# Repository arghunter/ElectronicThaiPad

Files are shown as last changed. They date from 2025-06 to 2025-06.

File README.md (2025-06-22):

# Electronic Thai Pad

A Thai pad that records and displays how hard you hit it with a strip of LEDs.

**What is a thai pad?**
- A thai pad is a handheld pad for kicking and punching
- However, it can be hard to guage how hard you are hitting to track your improvement



**What this electronic thai pad does**
- This project embedded an IMU (accelerometer) and a number of piezo sensors within a thai pad to detect the strengh of hits.
- It then uses an LED strip surrounding the pad to display visually the strength of hits
- Additionally, aim is very important, so the 5 piezo sensors, spread in a pentagon, can be used to highlight where on the pad your strike lands in order to help you center your following strikes

**Why I made this proejct**
As a fourth degree black belt, I value every source of feedback, but objective feedback can be difficult and expensive to acquire, so this is a cheap and low cost way to acquire objective feedback on my techniques.

## Pictures
### Full Project
- I would provide a 3d model, but it would just be an image of a thai pad, this system is mean to be fully embedded. However, below is a sketch of the sensor positioning. Additionally, the microcontroller will be surrounded in a TPU case to protect it from the repeated shocks.
- Note: These are meant to be flexible as there are many variation of thai pad designs.

### Wiring Diagram
- As the thai pad is rather large, a PCB will not work, instead I have attached a wiring diagram.


## BOM
| Part | Cost | Count | Notes | Link | Total |
|---|---|---|---|---|---|
| Adafruit Feather nRF52840 Sense | $39.50  | 1 | Already Owned | [Link](https://www.adafruit.com/product/4516) | $0.00 |
| Li-Po Battery | $5.95 | 1 | Already Owned | [Link](https://www.adafruit.com/product/4237) | $0.00 |
| STEVAL-MKI251A | $16.81  | 1 | Free Shipping | [Link](https://estore.st.com/en/steval-mki251a-cpn.html) | $16.81  |
| Piezo Sensor | $2.32 | 1 | 5-Pack | [Link](https://www.aliexpress.us/item/3256808935246513.html) | $2.32 |
| Neopixel Light Strip | $9.18 | 1 | 2m 60 | [Link](https://www.aliexpress.us/item/2251801850504415.html) | $9.18 |
| | | | | | |
| **Total:** | | | | | **$28.49** |

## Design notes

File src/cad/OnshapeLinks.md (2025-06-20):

Microcontroller Case: https://cad.onshape.com/documents/dade0f93471fa8ff7ce986ea/w/0de7b6a36b37bba335ba1247/e/2264d750831debf76f0489bb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

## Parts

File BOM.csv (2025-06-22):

Part | Cost | Count | Notes | Link | Total
Adafruit Feather nRF52840 Sense | $39.50 | 1 | Already Owned | https://www.adafruit.com/product/4516 | $0
Li-Po Battery | $5.95 | 1 | Already Owned | https://www.adafruit.com/product/4237 | $0
STEVAL-MKI251A | $16.81 | 1 | Free Shipping | https://estore.st.com/en/steval-mki251a-cpn.html | $16.81
Piezo Sensor | $2.32 | 1 | 5-Pack | https://www.aliexpress.us/item/3256808935246513.html | $2.32
Neopixel Light Strip | $9.18 | 1 | 2m 60 | https://www.aliexpress.us/item/2251801850504415.html | $9.18
Total: |  |  |  |  | $28.49

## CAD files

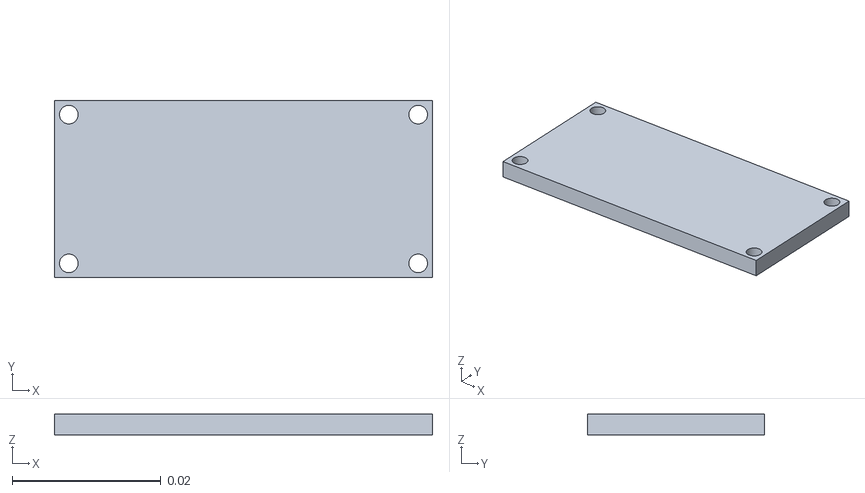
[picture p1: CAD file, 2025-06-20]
src/cad/MicrontrollerCaseTop.stl
0.0508 x 0.0239 x 0.0028

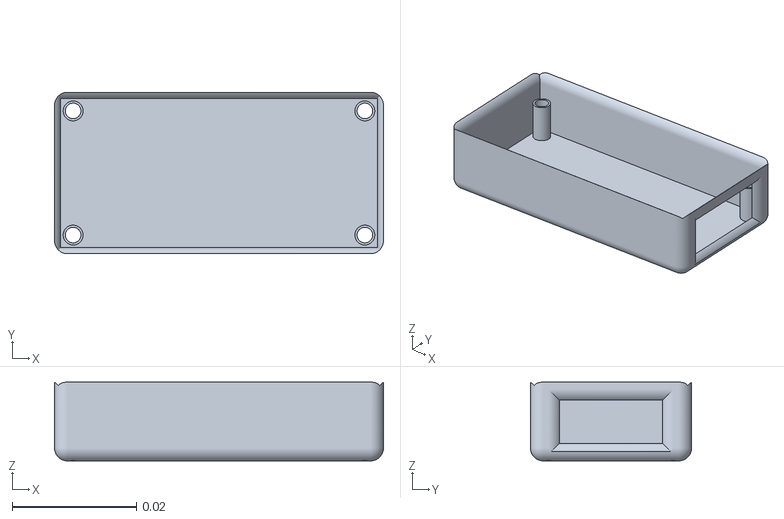
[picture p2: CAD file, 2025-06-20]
src/cad/MicrontrollerCaseBottom.stl
0.053 x 0.026 x 0.0127

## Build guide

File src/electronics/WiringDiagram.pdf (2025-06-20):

# Electronic Thai Pad Wiring

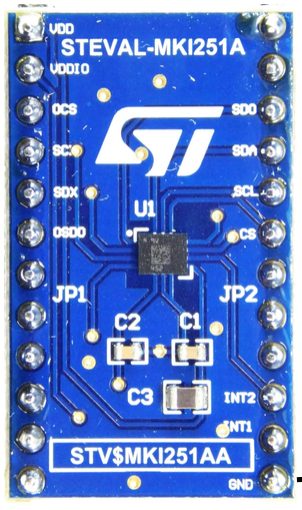
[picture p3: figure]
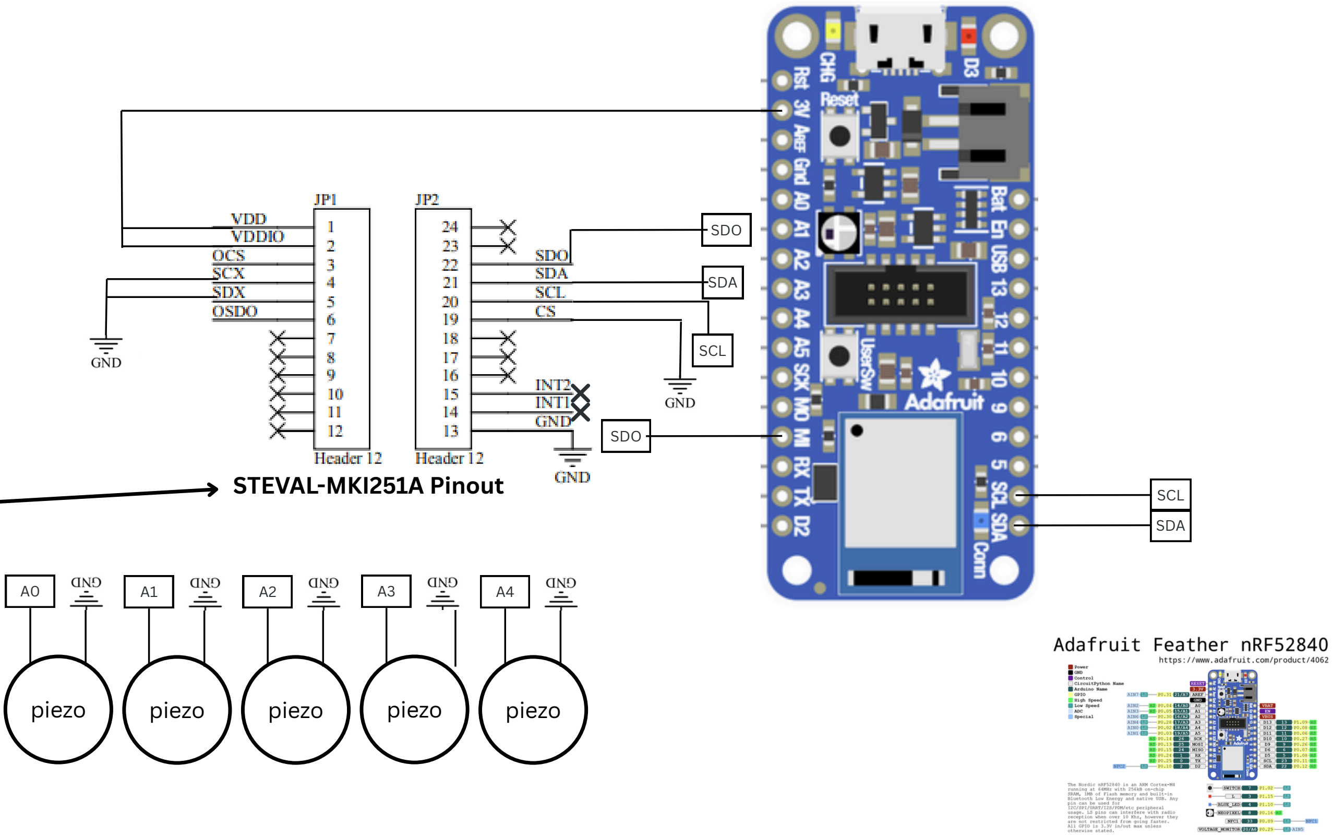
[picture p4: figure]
STEVAL-MKI251A Pinout; SDA; SCL; SDO; piezo

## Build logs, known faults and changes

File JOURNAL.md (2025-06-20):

---
title: "Electronic Thai Pad"
author: "Armaan Gomes"
description: "A Muay Thai Pad that uses a set of sensors to detect and respond to the strength of the hits."
created_at: "2025-06-9"
---

# June 9th
## Planning: 
- Needs to register hits
    - First Idea: IMU - Already have some Adafruit nrf 52840 sense boards (https://learn.adafruit.com/adafruit-feather-sense/overview) that would be great
    - Other Ideas:
        - Piezo sensors -  plan to hook up 4/5 to the ADCs of the nrf board for more detailed pressure/strike detection - Note: might need some voltage protection
        - FSR (Force Sensistive Resistors - A friend used these in one of their projects, but reportedly they aren't very precise, so probably won't use them.
     
- Signalling
    - LED strip around pad, neopixels embedded within pad below the fabric surface,
    - Can use bluetooth for web interface
    - First prototype will probably use serial while initial testing
 - Power
     - The nrf sense board already have a battery hookup and charger for lipo batteries
  
- Probably won't need a PCB just because the nrf sense boards already work so well.

## Programming:
- Found boards, updated bootloader
- Tried out the adafruit sensor demo
    - Took way to long to get the correct libaries installed
    -  
    - Need to note that the acceleration also includes gravity when stationary so I may need to offset that later
-  After that, tired out neopixel demo, needed to find correct neopixel configuration to use the onboard pin
-  Combined the two to make a system that reflects both the direction and magnitude of the acceleration on the IMu built into the board
    - Forgot to accout for negatives, which confused me for a bit
    - Squaring the values caused it to become too sensitive and also flashbang me,
    - Settled on less sensitive brightness and color control, with offsets to account for stationary moments.
        - Stationary:
            - Dim and single color
            - 
        - Accelerating:
            - Much brighter and between primary colors
            -   

## Pad Acquisition:
- I talked to my taekwondo instructor and he gave me 4 old pads to experiment with
    - 
## Initial Testing
- Shoved the sense board (feather) into the pad
    - Kinda messy for a first test but if it work it works. Note will need padding to protect board from impact
    - 
- Did a tad more coding, intially to use the serial plotter, but that sucks so I got a serial decoder in python and am using that for testing
- It works - But now I appear to be maxing out the sensor:
    - Despite hitting with different power, the accel always seems to be suspiciously similar 
    -  
    -  Read the data sheet and it looks like the imu is set to +-4G of acceleration so I need to find a way around that.
    -  Ok I found a way to increase the accel range to 16g, which is the max. SAadly, I'm still maxing it on some punches, maybe i should try some padding
        -    
- Padding in front of the sensor did not work, I think i need some sort of springy substance both infront and behind the sensor to act as mechanical dampers.

## Cadding
- I made a rough case that has a space for a sliding platform with springs to dampen impact.
- However, i am currently failing at both making a screw and making a spring I am using the sweep tool wrong somehow and will figure it out later
- 

1h planning (probably a little more than this)+1h coding + 0.5h Pad Acquisition+ 2h initial testing + 1 h CADding

**Time Spent: 5.5h**

# June 10th
## Cad Pain
- I really need to learn CAD for real.
- I got a spring set up in possible the most awful way posible
- Then for somethin reason I thought I could print this in 1 piece without supports
    - 
 - I also failed at screws again so I settled for dowels
 - I am also suspecting that I will need a high-G IMU like https://blog.st.com/lsm6dsv320x/
     - Its also smd so I have no shot of soldering that myself, so I'll probably need the expansion board
- Slice and printed for testing
    - 

1h Cadding + 0.5h Research/Parts Search
   
**Time Spent: 1.5h**

# June 12th
## Assembly
- Not too deep, everything generally fits. The dowels didn't print very well but thats fine.
  - 
  - 
  
## Wiring Diagram
-  Datasheet for imu: https://www.st.com/resource/ja/datasheet/lsm6dsv320x.pdf
-  Started work

**Time Spent: 0.5h**

# June 20th
## Wiring Diagram
- Made the wiring diagram, looked through datasheets and connected everything correctly
- Plan to directly solder to microcontroller due to the large distance from the micrcontroller to the peripherals
    -  May use a perf board if the wiring becomes too hairy.
 
## Case
- Minor tweaks, added stl files to repo, plan to print in TPU

**Time Spent: 1h**

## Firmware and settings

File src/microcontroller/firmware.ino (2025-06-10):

#include <Adafruit_LSM6DS33.h>
#include <Adafruit_LSM6DS3TRC.h>
#include <Adafruit_NeoPixel.h>


Adafruit_LSM6DS3TRC lsm6ds3trc; // accelerometer, gyroscope
Adafruit_LSM6DS33 lsm6ds33;

#define LED_PIN     8

#define LED_COUNT  1

#define BRIGHTNESS 50 // Set BRIGHTNESS to about 1/5 (max = 255)


Adafruit_NeoPixel strip(LED_COUNT, LED_PIN, NEO_GRBW + NEO_KHZ800);



float accel_x, accel_y, accel_z;
float gyro_x, gyro_y, gyro_z;


long int accel_array[6];
long int check_array[6]={0.00, 0.00, 0.00, 0.00, 0.00, 0.00};



bool new_rev = true;

void setup(void) {
  Serial.begin(115200);






  lsm6ds33.begin_I2C();
  lsm6ds33.setAccelRange(LSM6DS_ACCEL_RANGE_16_G);
  // check for readings from LSM6DS33
  sensors_event_t accel;
  sensors_event_t gyro;
  sensors_event_t temp;
  lsm6ds33.getEvent(&accel, &gyro, &temp);
  accel_array[0] = accel.acceleration.x;
  accel_array[1] = accel.acceleration.y;
  accel_array[2] = accel.acceleration.z;
  accel_array[3] = gyro.gyro.x;
  accel_array[4] = gyro.gyro.y;
  accel_array[5] = gyro.gyro.z;

  for (int i =0; i < 5; i++) {
    if (accel_array[i] != check_array[i]) {
      new_rev = false;
      break;
    }
  strip.begin();           // INITIALIZE NeoPixel strip object (REQUIRED)
  strip.show();            // Turn OFF all pixels ASAP
  strip.setBrightness(BRIGHTNESS);
  }
  // and we need to instantiate the LSM6DS3TRC
  if (new_rev) {
    lsm6ds3trc.begin_I2C();
  }


}

void loop(void) {

  sensors_event_t accel;
  sensors_event_t gyro;
  sensors_event_t temp;
  if (new_rev) {
    lsm6ds3trc.getEvent(&accel, &gyro, &temp);
  }
  else {
    lsm6ds33.getEvent(&accel, &gyro, &temp);
  }
  accel_x = accel.acceleration.x;
  accel_y = accel.acceleration.y;
  accel_z = accel.acceleration.z;
  strip.setPixelColor(0,strip.Color(abs(accel_x),   abs(accel_y),   abs(accel_z)));
  strip.setBrightness(abs(accel_x)*abs(accel_y)*abs(accel_z)+25);
  strip.show();
  

  Serial.print(accel_x);
  Serial.print(" ");
  Serial.print(accel_y);
  Serial.print(" ");
  Serial.print(accel_z);
  Serial.println();
  delay(30);
}

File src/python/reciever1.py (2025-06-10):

import serial
import matplotlib.pyplot as plt
import matplotlib.animation as animation
from collections import deque

# === Configuration ===
SERIAL_PORT = 'COM3'  
BAUD_RATE = 115200      
BUFFER_SIZE = 3000     


ser = serial.Serial(SERIAL_PORT, BAUD_RATE, timeout=1)


x_data = deque(maxlen=BUFFER_SIZE)
y_data = deque(maxlen=BUFFER_SIZE)
z_data = deque(maxlen=BUFFER_SIZE)
t_data = deque(maxlen=BUFFER_SIZE)

fig, ax = plt.subplots()
line_x, = ax.plot([], [], label='X')
line_y, = ax.plot([], [], label='Y')
line_z, = ax.plot([], [], label='Z')
ax.set_ylim(-160, 160) 
ax.set_xlim(0, BUFFER_SIZE)
ax.set_title("Real-time Accelerometer Data")
ax.set_xlabel("Sample")
ax.set_ylabel("Acceleration")
ax.legend(loc="upper right")


def update(frame):
    print("here")
    try:
        line = ser.readline().decode('utf-8').strip()
        print(line)
        parts = line.split()
        if len(parts) == 3:
            x, y, z = map(float, parts)
            x_data.append(x)
            y_data.append(y)
            z_data.append(z)
            t_data.append(len(t_data))

            line_x.set_data(range(len(x_data)), x_data)
            line_y.set_data(range(len(y_data)), y_data)
            line_z.set_data(range(len(z_data)), z_data)
    except Exception as e:
        print("Read error:", e)

    return line_x, line_y, line_z

ani = animation.FuncAnimation(fig, update, interval=30)
plt.tight_layout()
plt.show()

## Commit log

2025-06-20 Rename src/STEVAL-MKI251A Pinout.pdf to src/electronics/WiringDiagram.pdf
2025-06-20 Update and rename BOM2.csv to BOM.csv
    [BOM.csv]
